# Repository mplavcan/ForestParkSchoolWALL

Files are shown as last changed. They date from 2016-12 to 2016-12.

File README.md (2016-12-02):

ForestParkSchoolWALL
====================

Forest Park School Interactive Wall 

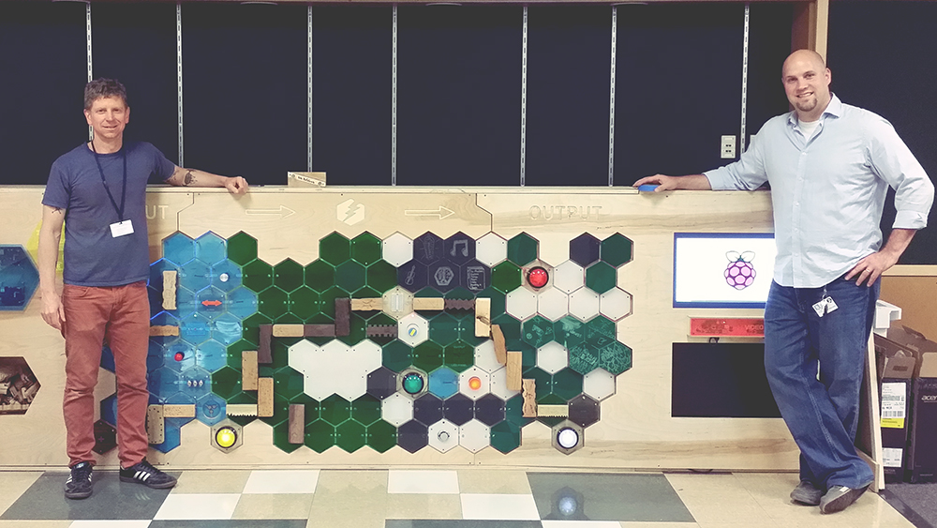
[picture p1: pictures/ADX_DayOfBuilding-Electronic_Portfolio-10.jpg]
ADX picture of full board in 2014


The Wall occupies a trophy case in the halls at [Forest Park Elementary School](http://www.pps.k12.or.us/schools/forestpark/)

It is designed to be an attraction to introduce students to the ideas of circuits while providing entertainment.

[Wall Conceptual Design](/documentation/Concept.md)
[2016 Board Electrical Redesign](/documentation/Redesign.md)
[Programming the Wall](/documentation/Programming.md)

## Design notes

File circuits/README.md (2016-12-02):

Wall Circuits
=============

The schematics provided here are in [Fritzing](http://fritzing.org/home/) format.

* Power_Supply - Auxiliary power for I/O components
* LED_board_1  - Switching circuit for Green/White LED arrays (2 each)
* LED_board_2  - Switching circuit for Red LED arrays (4 total)
  Because board 2 uses PNP transistors, output _low_ turns LED _on_

Only the schematics are provided:  The Breadboard/PCB ascpects of the files are not placed or routed, as they would not physcially match the devices as-built.

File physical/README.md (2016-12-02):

Physical Source Code
====================

These files contain the instructions for creating plastic itmes for the Wall.

The *.scad files are [OpenSCAD format](http://www.openscad.org), and are designed to be 3D-printed using a standard extrusion printer in PLA plastic.

The *.svg are Scalable Vector Graphics format, and are designed to be cut from acrylic using a high-power laser cutter.

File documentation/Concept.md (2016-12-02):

Board Design
============

Board concept was created by [Travis Feldman](http://travisfeldman.org) in June 2014

The board consists of an artistic map of the northwest corner of the state of Oregon, laid out using hexagons:

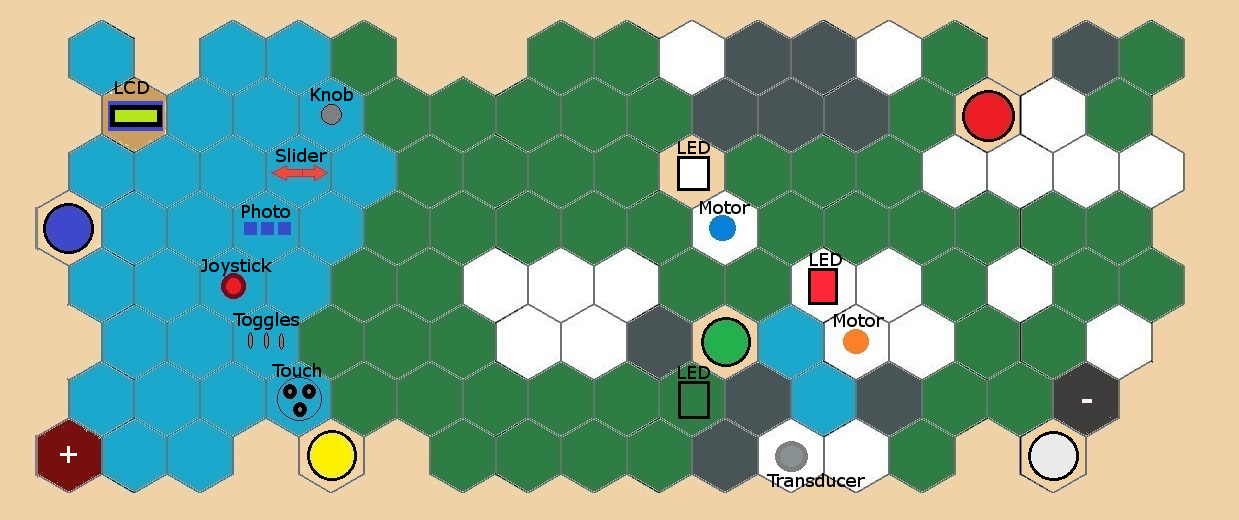
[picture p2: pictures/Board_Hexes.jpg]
Board front showing hexes


On the left (ocean) side are a "battery positive" terminal and six input types:
* Rotary potentiometer (knob)
* Linear potentiometer (slider)
* Photosensors (three)
* Digital (arcade-style) joystick
* Toggle switches (three)
* Force sensors (three)

On the right (mountain) side are "battery negative" terminal and six outputs:
* LED array (white)
* Motor (blue spinner)
* LED array (red)
* Motor (red spinner)
* LED array (green)
* Transducer (speaker)

The board also has five large illuminated colored buttons (Red, Green, White, Blue, Yellow) that are associated with electroluminescent wire wrapped under the hexes.  

A LCD with a selectable color backlight occupies a hex in the upper-left corner of the board.

The circuits allow any one of the input types to be connected to one of the outputs using a series of wooden blocks to bridge across the intervening hexes.  When a full connection between the positive/input/output/negative terminals are made, the input will manipulate the output.

All components are software controllable by the Arduino, independent of each other.  While the students appear to be creating circuits, in fact the software is making the decision about what to activate.  This also prevents accidental damage from being done by "short circuits"

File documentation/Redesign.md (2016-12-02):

2016 Board Redesign
===================

Over the last two years, the Wall had fallen into disrepair. 
Forest Park Elementary approached the Intel Oregon Makers group in early 2016 to repair the Wall.

With very little circuit documentation, and a large amount of wiring to sort through and test, the group opted to redesign the electrical portions of the Wall.  A quick overview of the previous design:

I/O was distributed through six Arduinos:
* One had a motor shield to handle the motors
* One had a [Sparkfun El Escudo Dos](https://www.sparkfun.com/products/10878) to control the EL wire
* Four others handled miscellaneous I/O

Lots of this:

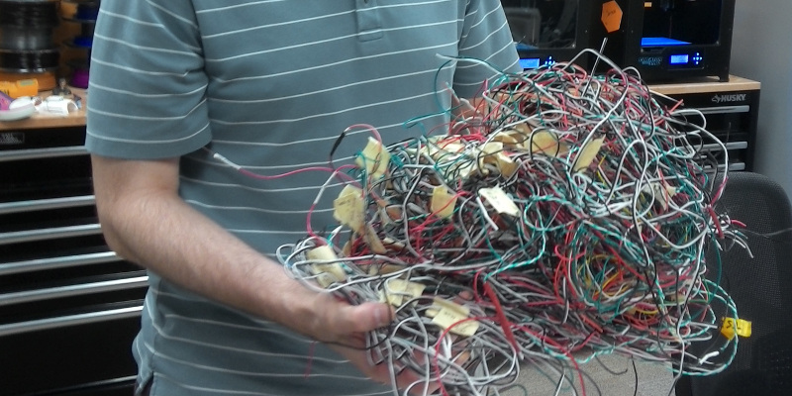
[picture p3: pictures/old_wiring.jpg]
Bird's nest of Wire


The replacement design consolidated the control into a single [Intel Arduino 101](http://www.intel.com/content/www/us/en/do-it-yourself/arduino-101.html), keeping the Sparkfun board for EL control, and handling the other I/O via expansion boards:
* Four [Sparkfun SX1509 I2C 16-channel digital I/O](https://www.sparkfun.com/products/13601)
* Two [Adafruit ADS1015 I2C 4-channel 12-bit analog inputs](https://www.adafruit.com/products/1083)
* One [Adafruit TCA9685 I2C 16-channel PWM driver outputs](https://learn.adafruit.com/16-channel-pwm-servo-driver/overview)
* One [Adafruit TB6612 2-channel motor controller](https://www.adafruit.com/products/2448)
* One [Adafruit TCA9548a I2C multiplexer](https://learn.adafruit.com/adafruit-tca9548a-1-to-8-i2c-multiplexer-breakout/overview) (to avoid multiple devices with the same address conflicting on the I2C bus)

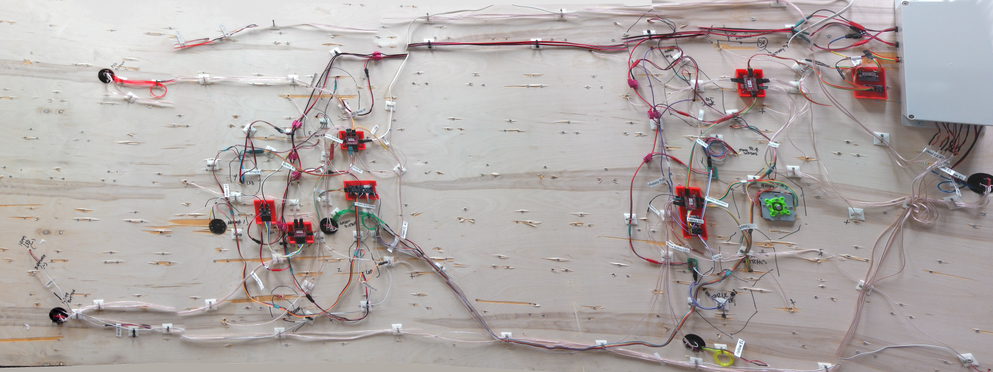
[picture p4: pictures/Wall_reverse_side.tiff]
Reverse side of Wall showing wiring


The group added a SeeedStudio Grove I2C RGB LCD display under a clear hex in the upper left corner of the Wall to provide additional visual feedback.

The consolidation of Arduino code into a single device allows the easy development a single Wall object in the C++ code that programs can interact with.

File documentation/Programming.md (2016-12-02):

Programming
============

Arduino and Friends
-------------------
The Wall is powered by a single [Intel Arduino 101 "Curie"](https://www.arduino.cc/en/Guide/Arduino101)
 assisted by several I/O expansion boards.  The libraries for these  will need to be included in any sketch in order for the Wall to function correctly:
* [Sparkfun SX1509 IO Expander](https://github.com/sparkfun/SparkFun_SX1509_Arduino_Library)
* [Adafruit ADS1X15](https://github.com/nipoutch/Adafruit_ADS1015)
* [Adafruit PWM Servo Driver Library](https://github.com/adafruit/Adafruit-PWM-Servo-Driver-Library)
* [Seeedstudio Grove I2C RGB Backlit LCD](https://github.com/Seeed-Studio/Grove_LCD_RGB_Backlight)

Toolchain
---------
While the stock Arduino IDE can be used, the code in this repository was developed using the following tools:
* [Microsoft Visual Studio Community Edition](https://www.visualstudio.com/en-us/products/visual-studio-community-vs.aspx)
* [Visual Micro](http://www.visualmicro.com/)
* [Google Test](https://github.com/google/googletest)
* [Jetbrains Resharper C++](https://www.jetbrains.com/resharper-cpp/)

Repository Setup
----------------
The tests also use the [Arduino-mock library](https://github.com/balp/arduino-mock), which is installed as a Git sub-repository in this repo.  To install it, perform these steps after cloning:

```
   git submodule init
   git submodule update
```

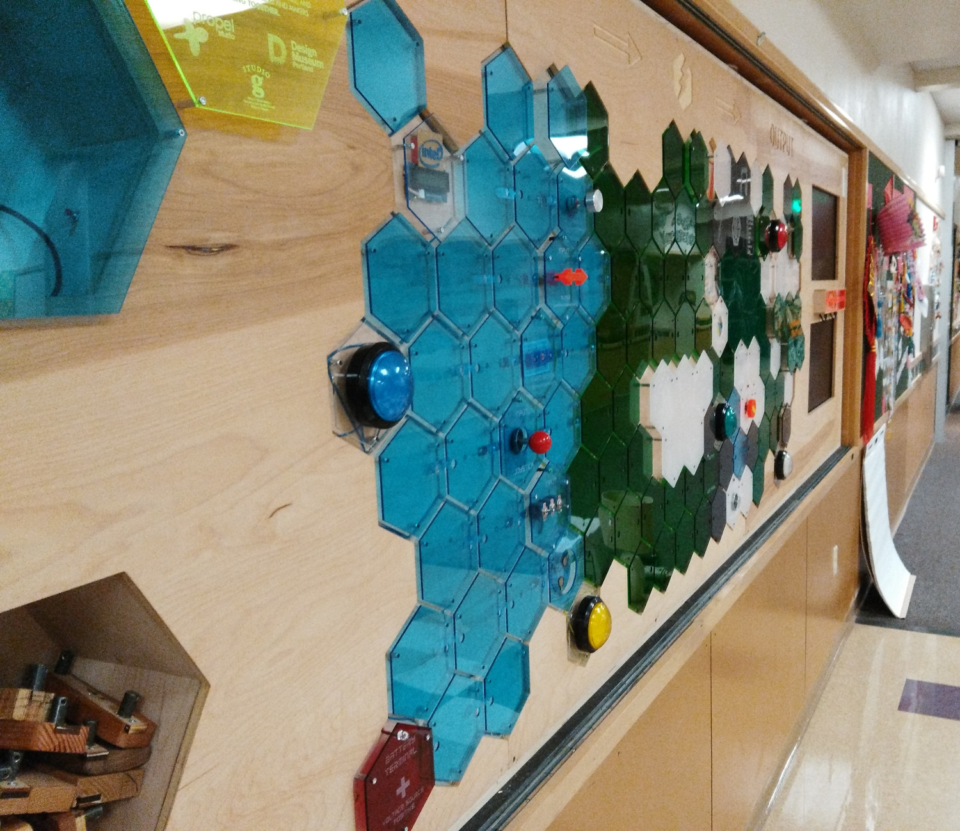
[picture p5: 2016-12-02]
pictures/Wall_sideways.jpg

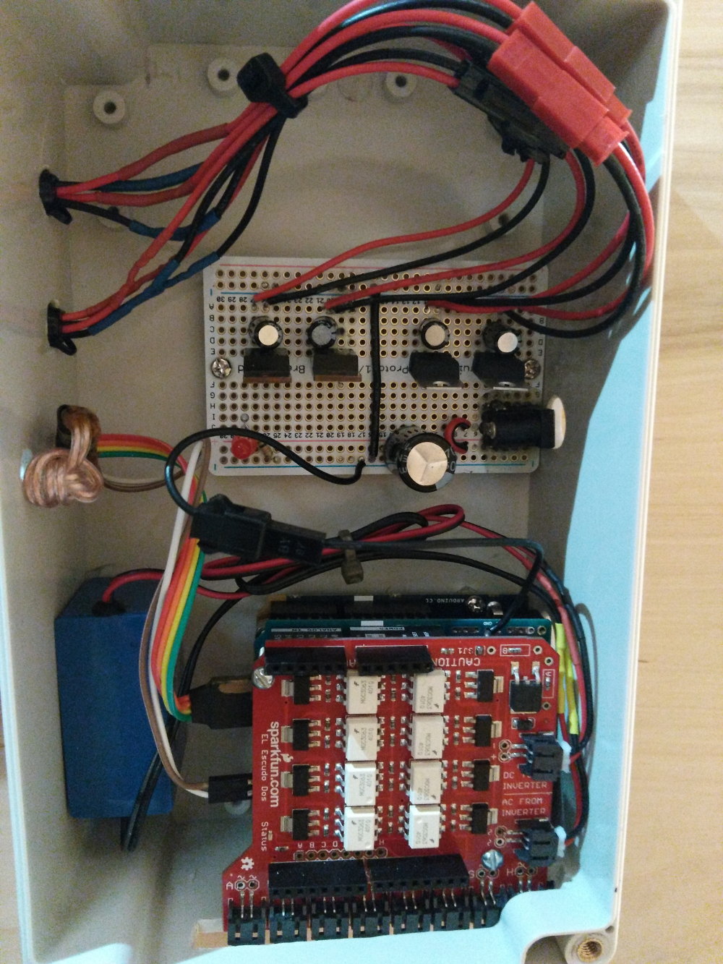
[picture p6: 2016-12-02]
pictures/Power_supply_Arduino.jpg

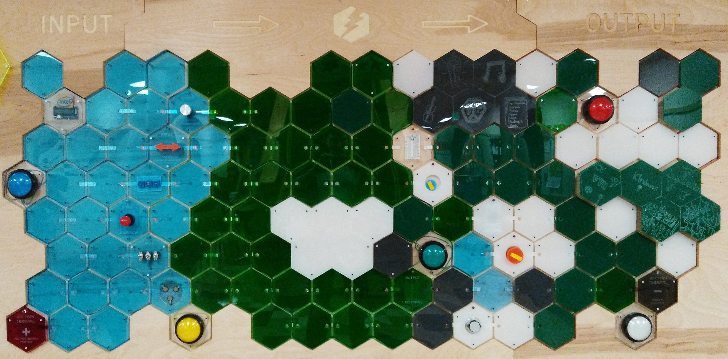
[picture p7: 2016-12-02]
pictures/Wall_closeup.jpg

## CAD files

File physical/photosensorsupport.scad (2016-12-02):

// Raised support for photosensor
//

support_side = 20;
support_height = 11;

hole_radius = 1.5;
hole_offset = 3.8;
INF = 100000;

difference() {
    cube([support_side, support_side, support_height], center = true);
    translate([hole_offset, 0, 0]) cylinder(r=hole_radius, h=INF, center=true, $fn=20);
    translate([-hole_offset, 0, 0]) cylinder(r=hole_radius, h=INF, center=true, $fn=20);
}

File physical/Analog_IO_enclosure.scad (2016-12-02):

// Case enclosure for:
//   Sparkfun SX1509 I/O Expander board
//   Two Adafruit ADS1015 Analog Input boards
//

// Number of facets for cylinders
$fn = 20;

enclosure_x_dim = 120;
enclosure_y_dim = 50;
enclosure_height = 20;

sx1509_standoff_x_offset = 15.4;
sx1509_standoff_y_offset = 10.4;
standoff_hole_radius = 1;

ads1015_standoff_y_offset = 11.5;

mount_x_offset = 21;
mount_y_offset = 16;
mount_hole_radius = 1.6;

base_thickness = 3;
wall_width = 2;
wall_height = enclosure_height;

BELOW_PLANE = -1;
INF = 100000;

io_shift = 25;
io_width = 25;

difference() {
    // outer extents
    cube([enclosure_x_dim ,enclosure_y_dim ,enclosure_height], center = true);

    // cutout inside to form walls
    translate([0,   0, base_thickness])cube([enclosure_x_dim -(2*wall_width),enclosure_y_dim -(2*wall_width), wall_height], center = true);

    translate([io_shift,0,0]){

        // I/O side cuts
        translate([1.5, 0, base_thickness])cube([30,INF,wall_height], center = true);
        translate([0,   2, base_thickness])cube([INF,15,wall_height], center = true);
         
        // SX1509 mounting holes
        translate([sx1509_standoff_x_offset,sx1509_standoff_y_offset, BELOW_PLANE])   cylinder(r=standoff_hole_radius, h=INF, center=true);
        translate([sx1509_standoff_x_offset,-sx1509_standoff_y_offset, BELOW_PLANE])  cylinder(r=standoff_hole_radius, h=INF, center=true);
        translate([-sx1509_standoff_x_offset,sx1509_standoff_y_offset, BELOW_PLANE])  cylinder(r=standoff_hole_radius, h=INF, center=true);
        translate([-sx1509_standoff_x_offset,-sx1509_standoff_y_offset, BELOW_PLANE]) cylinder(r=standoff_hole_radius, h=INF, center=true);

        // ADS1015 #1 mounting holes
        translate([sx1509_standoff_x_offset-(io_shift+2*io_width),ads1015_standoff_y_offset, BELOW_PLANE])  cylinder(r=standoff_hole_radius, h=INF, center=true);
        translate([sx1509_standoff_x_offset-(io_shift+2*io_width),-ads1015_standoff_y_offset, BELOW_PLANE]) cylinder(r=standoff_hole_radius, h=INF, center=true);

        // ADS1015 #2 mounting holes
        translate([sx1509_standoff_x_offset-(io_shift+io_width),ads1015_standoff_y_offset, BELOW_PLANE])  cylinder(r=standoff_hole_radius, h=INF, center=true);
        translate([sx1509_standoff_x_offset-(io_shift+io_width),-ads1015_standoff_y_offset, BELOW_PLANE]) cylinder(r=standoff_hole_radius, h=INF, center=true);
            
        // Enclosure mounting holes
        translate([mount_x_offset,mount_y_offset, BELOW_PLANE])   cylinder(r=mount_hole_radius, h=INF, center=true);
        translate([mount_x_offset,-mount_y_offset, BELOW_PLANE])  cylinder(r=mount_hole_radius, h=INF, center=true);
        translate([-mount_x_offset-(2*io_width),mount_y_offset, BELOW_PLANE])  cylinder(r=mount_hole_radius, h=INF, center=true);
        translate([-mount_x_offset-(2*io_width),-mount_y_offset, BELOW_PLANE]) cylinder(r=mount_hole_radius, h=INF, center=true);
    }
}

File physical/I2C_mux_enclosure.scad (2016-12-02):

// Case enclosure for:
//   Adafruit TCA9548a I2C multiplexer board
//

// Number of facets for cylinders
$fn = 20;

enclosure_x_dim = 60;
enclosure_y_dim = 50;
enclosure_height = 20;

base_thickness = 3;
wall_width = 2;
wall_height = enclosure_height;

tca9548_standoff_xoffset = 12.5;
tca9548_standoff_yoffset = 12.5;
standoff_hole_radius = 1;

mount_x_offset = 21;
mount_y_offset = 16;
mount_hole_radius = 1.6;

BELOW_PLANE = -1;
INF = 100000;

difference() {
     // outer extents
    cube([enclosure_x_dim ,enclosure_y_dim ,enclosure_height], center = true);
    translate([0,   0, base_thickness])cube([56,46,20], center = true);
 
    // cutout inside to form walls
    translate([0,   0, base_thickness])cube([enclosure_x_dim -(2*wall_width),enclosure_y_dim -(2*wall_width), wall_height], center = true);
 
    // TCA9548 mounting hols
    translate([tca9548_standoff_xoffset,tca9548_standoff_yoffset,-1])   cylinder(r=standoff_hole_radius, h=20, center=true, $fn=20);
    translate([tca9548_standoff_xoffset,-tca9548_standoff_yoffset,-1])  cylinder(r=  standoff_hole_radius, h=20, center=true, $fn=20);

    // Enclosure mounting holes
    translate([mount_x_offset,mount_y_offset, BELOW_PLANE])   cylinder(r=mount_hole_radius, h=INF, center=true);
    translate([mount_x_offset,-mount_y_offset, BELOW_PLANE])  cylinder(r=mount_hole_radius, h=INF, center=true);
    translate([-mount_x_offset,mount_y_offset, BELOW_PLANE])  cylinder(r=mount_hole_radius, h=INF, center=true);
    translate([-mount_x_offset,-mount_y_offset, BELOW_PLANE]) cylinder(r=mount_hole_radius, h=INF, center=true);
}

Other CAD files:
physical/Digital_IO_enclosure.scad
physical/PWM_IO_enclosure.scad

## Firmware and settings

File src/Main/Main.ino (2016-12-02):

// Main program for Forest Park School Wall
//
#include <Arduino.h>
#include <Wire.h>
#include <rgb_lcd.h>
#include <SparkFunSX1509.h>
#include <Adafruit_PWMServoDriver.h>
#include <Adafruit_ADS1015.h>
#include "DeviceFactory.h"
#include "Wall.h"
#include "FunWithCircuits.h"

FunWithCircuits *app;

void setup() {
    Serial.begin(115200);
    delay(1000);
    Serial.println("Starting setup()");
    Serial.println("Forest Park Circuit Wall starting up");

    app = new FunWithCircuits((new Wall)->usingFactory(new DeviceFactory));

    if (!app->setup())
    {
        while (true)
        {
            Serial.println("Initialization of I2C devices failed");
            delay(ONE_SECOND);
        }
    }
    Serial.println("Exiting setup()");
}

void loop(void)
{
    app->loop(millis());
    delay(ONE_HUNDREDTH_SECOND);
}

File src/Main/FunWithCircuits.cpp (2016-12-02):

// Application object for Forest Park School Wall
//
#include "FunWithCircuits.h"

bool FunWithCircuits::setup(void)
{
    if (!wall->initialize())
        return false;
    wall->lcdSetBacklightColor(0, 255, 50);
    wall->lcdPrintAt(0, 0, "Forest Park");
    wall->lcdPrintAt(0, 1, "Elementary");
    wall->turnIndicatorOn(INDICATE_NEGATIVE_POLE);
    wall->turnIndicatorOn(INDICATE_POSITIVE_POLE);
    return true;
}

void FunWithCircuits::driveMotor(wall_motor motor, unsigned int value, const unsigned int midpoint)
{
    bool motorIsClockwise = (value > midpoint);
    unsigned int motorSpeed = (value % midpoint);
    if (motorIsClockwise)
        wall->setMotorDirectionClockwise(motor);
    else
        wall->setMotorDirectionCounterClockwise(motor);
    wall->setMotorSpeed(motor, motorSpeed);
}

void FunWithCircuits::driveTransducer(unsigned int value, const unsigned int midpoint)
{
    if (value > midpoint)
        wall->turnTransducerOn();
    else
        wall->turnTransducerOff();
}

void FunWithCircuits::driveTwoPartLED(led_array array, unsigned int value, const unsigned int midpoint)
{
    if (value > 0)
        wall->turnOnLEDarray(array, LEFT_SIDE);
    else
        wall->turnOffLEDarray(array, LEFT_SIDE);

    if (value > midpoint)
        wall->turnOnLEDarray(array, RIGHT_SIDE);
    else
        wall->turnOffLEDarray(array, RIGHT_SIDE);
}

void FunWithCircuits::driveFourPartLED(unsigned int value, const unsigned int midpoint)
{
    if (value > 0)
        wall->turnOnLEDarray(RED_LED, LOWER_LEFT_SIDE);
    else
        wall->turnOffLEDarray(RED_LED, LOWER_LEFT_SIDE);

    if (value > (midpoint / 2))
        wall->turnOnLEDarray(RED_LED, LEFT_SIDE);
    else
        wall->turnOffLEDarray(RED_LED, LEFT_SIDE);

    if (value > midpoint)
        wall->turnOnLEDarray(RED_LED, RIGHT_SIDE);
    else
        wall->turnOffLEDarray(RED_LED, RIGHT_SIDE);

    if (value > (3 * midpoint / 2))
        wall->turnOnLEDarray(RED_LED, LOWER_RIGHT_SIDE);
    else
        wall->turnOffLEDarray(RED_LED, LOWER_RIGHT_SIDE);
}

unsigned int FunWithCircuits::getInputHexValue(void)
{
    switch (energizedInput)
    {
    case KNOB_HEX:
        return wall->getKnobPosition();
    case SLIDER_HEX:
        return wall->getSliderPosition();
    case PHOTO_SENSOR_HEX:
        return (wall->getPhotoSensorValue(LEFT_PHOTO) +
            wall->getPhotoSensorValue(CENTER_PHOTO) +
            wall->getPhotoSensorValue(RIGHT_PHOTO));
    case TOUCH_SENSOR_HEX:
        return (wall->getTouchSensorValue(LEFT_TOUCH) +
            wall->getTouchSensorValue(BOTTOM_TOUCH) +
            wall->getTouchSensorValue(RIGHT_TOUCH));
    case JOYSTICK_HEX:
        return PWM_FULL_DUTY_CYCLE *
            (wall->isJoystickDown() ||
                wall->isJoystickLeft() ||
                wall->isJoystickRight() ||
                wall->isJoystickUp());
    case TOGGLE_SWITCH_HEX:
        return (
            (wall->isToggleOn(LEFT_TOGGLE)   * (PWM_FULL_DUTY_CYCLE / 2)) +
            (wall->isToggleOn(CENTER_TOGGLE) * (PWM_FULL_DUTY_CYCLE / 4)) +
            (wall->isToggleOn(RIGHT_TOGGLE)  * (PWM_FULL_DUTY_CYCLE / 8)));
    default: return 0;
    }
}

unsigned int FunWithCircuits::sawtoothCycle(unsigned long currentTime)
{
    int cycle = currentTime % PWM_FULL_DUTY_CYCLE;
    if (cycle < PWM_FULL_DUTY_CYCLE / 2)
        return cycle;
    else
        return (PWM_FULL_DUTY_CYCLE - cycle);
}

input_hex FunWithCircuits::findConnectedInputHex(void)
{
    for (int hex = KNOB_HEX; hex <= TOUCH_SENSOR_HEX; hex++)
    {
        input_hex in = static_cast<input_hex>(hex);
        circuit_end end = wall->leftCircuitForInput(in);
        if (wall->isCircuitConnected(CIRCUIT_POSITIVE_POLE, end))
            return in;
    }
    return NO_INPUT;
}
output_hex FunWithCircuits::findConnectedOutputHex(void)
{
    for (int hex = WHITE_LED_HEX; hex <= TRANSDUCER_HEX; hex++)
    {
        output_hex out = static_cast<output_hex>(hex);
        circuit_end end = wall->rightCircuitForOutput(out);
        if (wall->isCircuitConnected(CIRCUIT_NEGATIVE_POLE, end))
            return out;
    }
    return NO_OUTPUT;
}

void FunWithCircuits::driveOutputHex(unsigned int value)
{
    const int midpoint = 2048;
    const int motorMidpoint = 500;
    switch (energizedOutput)
    {
    case BLUE_MOTOR_HEX:
        driveMotor(BLUE_MOTOR, value, motorMidpoint);
        break;
    case ORANGE_MOTOR_HEX:
        driveMotor(ORANGE_MOTOR, value, motorMidpoint);
        break;
    case TRANSDUCER_HEX:
        driveTransducer(value, midpoint);
        break;
    case WHITE_LED_HEX:
        driveTwoPartLED(WHITE_LED, value, midpoint);
        break;
    case GREEN_LED_HEX:
        driveTwoPartLED(GREEN_LED, value, midpoint);
        break;
    case RED_LED_HEX:
        driveFourPartLED(value, midpoint);
        break;
    default: break;
    }
}

void FunWithCircuits::collectCircuitConnections(void)
{
    energizedInput = findConnectedInputHex();
    energizedOutput = findConnectedOutputHex();
    bool inputAndOutputConnected = wall->isCircuitConnected(
        wall->rightCircuitForInput(energizedInput),
        wall->leftCircuitForOutput(energizedOutput));

    circuitComplete = inputAndOutputConnected &&
        (energizedInput != NO_INPUT) &&
        (energizedOutput != NO_OUTPUT);
}

void FunWithCircuits::lightIndicatorsForConnectedCircuits(unsigned long currentTime)
{
    if (circuitComplete)
    {
        indicator_led inputLamp = wall->indicatorforInput(energizedInput);
        indicator_led outputLamp = wall->indicatorForOutput(energizedOutput);
        wall->turnIndicatorOn(inputLamp);
        wall->turnIndicatorOn(outputLamp);
    }
    else
    {
        for (int hex = KNOB_HEX; hex <= TOUCH_SENSOR_HEX; hex++)
        {
            input_hex in = static_cast<input_hex>(hex);
            indicator_led inputLamp = wall->indicatorforInput(in);
            if (in == energizedInput)
                wall->setIndicatorBrightness(inputLamp, sawtoothCycle(currentTime));
            else
                wall->setIndicatorBrightness(inputLamp, 0);
        }
        for (int hex = WHITE_LED_HEX; hex <= TRANSDUCER_HEX; hex++)
        {
            output_hex out = static_cast<output_hex>(hex);
            indicator_led outputLamp = wall->indicatorForOutput(out);
            if (out == energizedOutput)
                wall->setIndicatorBrightness(outputLamp, sawtoothCycle(currentTime));
            else
                wall->setIndicatorBrightness(outputLamp, 0);
        }
    }
}


EL_wire FunWithCircuits::chooseELwireForButton(large_button color)
{
    switch (color)
    {
    case RED_BUTTON: return RED_WIRE_ONE;
    case YELLOW_BUTTON: return YELLOW_WIRE;
    case WHITE_BUTTON: return WHITE_WIRE;
    case BLUE_BUTTON: return BLUE_WIRE_ONE;
    case GREEN_BUTTON: return GREEN_WIRE_ONE;
    default: return RED_WIRE_TWO;
    }
}
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

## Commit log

2014-06-27 Create Arduino#1
    Demo Mode - will add full I2C instructions soon... This is the Master of the I2C (Integer-Integrated Circuit), the other Slave Arduinos will be numbered #2-5.
2014-06-27 Create Arduino#2Demo
    This is demo mode.
2014-06-27 Create Arduino#3Demo
2014-06-27 Create Arduino#4Demo
2014-06-27 Create Arduino#5Demo
2014-06-27 Create Arduino#6_ElWire_demo
2016-07-11 Wall 2016 Redesign: Added new README and documentation Added datasheets for new components Added Grove I2C LCD library files Added pictures for board design Removed existing Arduino sketches
2016-07-12 Added 3D-printing and laser-cutting source code
    [Analog_IO_enclosure.scad, Digital_IO_enclosure.scad, I2C_mux_enclosure.scad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]
2016-07-13 Switched relative paths in documentation to absolute
2016-07-13 Added links for Sparkfun/Adafruit boards to documentation
2016-07-13 Added Wall pin and device definitions
2016-07-14 Fixed copy/paste error in I2C defines
2016-07-15 Added Wall object project Added Google Test framework and unit test module
2016-07-18 Fixed typo in pin definitions
2016-07-18 Added independent project files - Main (Useable wall) - DeviceTest (Visible integration test of wall components) - WallTest (Unit tests of Wall software object)
2016-09-02 Added Arduino mocking libraries Fixed path dependencies between Arduino projects and Google Test projects Added simple mocking test for Wall object
    [DeviceTest.ino, Main.ino]
2016-09-28 Rename file to match case
2016-09-29 Added units tests around I2C multiplexer behavior (not TDD, method copied)
2016-09-29 Added Fritizing circuit diagrams
    [LED_board_1.fzz, LED_board_2.fzz, Power_Supply.fzz]
2016-10-04 Growing LED array interface, device dependency injection
2016-10-04 Parameterized LED array tests Made interface define values uniform to avoid arbitrary lookup functions
2016-10-11 Indexed IO expansion devices in array
2016-10-12 Extracted Interface from DeviceFactory Cleaned up dependencies
2016-10-12 Split implementation and interface for DeviceFactory
2016-10-15 Added first motor test Changed expectation on I2C endtransmission to be exact
2016-10-16 Extacted motor control parameters Moved I2C bus lookup inside setMultiplexerI2Cbus
2016-10-16 Added Motor rever/sestop methods
2016-10-17 Fixed Red LED array being active low
2016-10-17 Changed interface for LED arrays to specify array and section
2016-10-17 Changed motor speed to be unsigned
2016-10-17 Fixed definition of Adafruit PWM mock
2016-10-17 Added first Transducer test Includes instantiation of 9685 PWM mock
2016-10-18 Added constants for PWM duty cycle
2016-10-18 Added initialization code for LED/Motor/transducer output pins
2016-10-18 Added PWM output controls for indicator lamps
2016-10-19 Changed constants around device usage to index-based rather than I2C address
2016-10-19 Added toggle switch methods
2016-10-19 Added toggle switch initialization
2016-10-19 Added mocked ADS1015 to device factories
2016-10-19 Added ADS1015 device initialization and access methods
2016-10-19 Fixed pin assignment bug in Red LED array
2016-10-19 Added photoresistor inputs Added force sensor inputs
2016-10-19 Added grid circuit plumbing/tests
2016-10-19 Added large button input methods
2016-10-19 Added large button illumination
2016-10-19 Fixed dependencies for Arduino builds
2016-10-19 Added electroluminescent wire control
2016-10-19 Added pin initialization for large buttons Added pin initialization for EL wire
2016-10-20 Added retry code for I2C communications bug
2016-10-20 Moved constant for Wire library testing, fixed value
2016-10-20 Fixed polarity of I2C mux slection loop
2016-10-20 Fixed project dependency issue for Arduino builds
    [DeviceTest.ino, Main.ino]
2016-10-20 Updated DeviceTest to match Main project dependencies
2016-10-21 Added I2C initialization to Wall
2016-10-21 Moved EL wire enum to start at 0
2016-10-21 Ported IO device test code into Wall object calls[C
2016-10-21 Removed all relative paths from files Fixed Project import/resource paths Eliminated bifurcation of WallCore (renamed Wall)
    [DeviceTest.ino]
2016-10-21 Reverted path hacks to arduino-mock sub-repo
2016-10-21 Changed release order of mock devices to LIFO allocation order
2016-10-22 Added mock Grove RGB LCD device
2016-10-22 Added LCD printAt method to flesh out Grove interface
2016-10-22 Added LCD support to DeviceFactory Moved LCD initialization to beginning of wall initialization sequence
2016-10-22 Added LCD calls to DeviceTest
2016-10-22 Moved Grove LCD library to Arduino local library path (removed from repo)
2016-10-22 Added mapping function between circuit points and indicator LEDs Changed all touch sensor constants to use "TOUCH" instead of "PRESSURE"
2016-10-25 Updated DeviceTest for new methods
2016-10-25 Created main program for circuit wall interactions
2016-10-25 Added constants for Main circuit program
2016-10-26 Fixed bug with motor selection
2016-10-26 Updated DeviceTest: Bug fixes found during integration Clarified debug serial messages by adding strings Disabled BLue Motor (broken on board)
    [DeviceTest.ino]
2016-10-26 Changed constants to reflect "Motor 1" is Orange
2016-10-26 Changed grid to pull negative pin low and only test non-battery grid points
2016-11-03 Fixed serial init in Main
    [Main.ino]
2016-11-03 Changed LED array writes to analog calls (for adjusting brightness via PWM)
2016-11-03 Added Timer Class (w/unit tests)
2016-11-03 Moved TimerTest project to own directory
2016-11-03 Used Timer class in Main project
2016-11-03 Main: Turned off all output hexes when no circuit path exists
2016-11-03 Main: Refactored for clarity Reduced timer delay to .01s
2016-11-03 Reversed control pins for motor 1 to correct direction
2016-11-04 Converted LED arrays to use analog pin writes to allow brightness control
2016-11-04 DeviceTest: Re-enabled blue motor
2016-11-06 Moved indicator/circuit lookup tables into static functions in Wall Updated DeviceTest/Main for new lookups
2016-11-06 Fixed defects with enerated value comparisons
    [Main.ino]
2016-11-06 Clarified variable intentions Fixed bug in indicator off loop
    [DeviceTest.ino]
2016-11-08 Fixed copy/paste bug in circuit connection trigger
    [DeviceTest.ino]
2016-11-08 Added missing test for PWM initialization Added appropriate reset calls to PWM device Removed pin-by-pin reset
2016-11-08 Added default state writes (off) for buttons, LEDs, indicators, transducer
2016-11-16 Fixed polarity of reset for red LED array
2016-11-16 Refactored LED initialization routine to use normalized values
2016-11-22 DeviceTest: Widened deadzone and added maximum speed for motors
2016-11-22 Main: Fixed bugs in circuit connection logic
    [Main.ino]
2016-11-22 Main: Illuminate large buttons when pressed
2016-11-22 Main: Added EL wire selection by button and better motor thresholds
2016-11-22 DeviceTest: Added workaround for LCD initialization issue
    [DeviceTest.ino]
2016-11-22 Main: Extracted circuit application code to separate object
2016-11-22 Moved Circuit application to separate module
